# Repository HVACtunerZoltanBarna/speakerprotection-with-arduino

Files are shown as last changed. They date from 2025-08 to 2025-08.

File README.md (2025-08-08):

# speakerprotection-with-arduino
My Arduino based Speaker protection for 4 channels.
AVE !
I am happy to share my project with you. If you use or upgrade it I would be happy if you give some feeback to me just to see how it works around the world:).

So it is an arduino based speaker protection. I use it in my custom made amp, and works well from 2021. Simple and rigid...
You can find here kicad model as well.
What it does?
Protects the speaker from those current whose does not make movement. So protects it from burning.
Topology is:
Amplifier outputs max 4 channel. But can use for less. (An for more as well if you modify the code and use more analogInputs :) )
The voltage from amp output must go to a voltage divided RC filter.
If the AC contains too much DC (or the frequency is extremely low) that can be seen on the capacitor it opens a relay. Normally DC part of the current is 0 so the speakers can move and cool themself.
Just an advice. It is fine to calibrate the inputs with freq generator and power supply for example.
And dont forget about the input voltage of Arduino. The analogRead compares
voltage to Vref. If Supply is too low Vref will lower too.

Bye. Z. :)

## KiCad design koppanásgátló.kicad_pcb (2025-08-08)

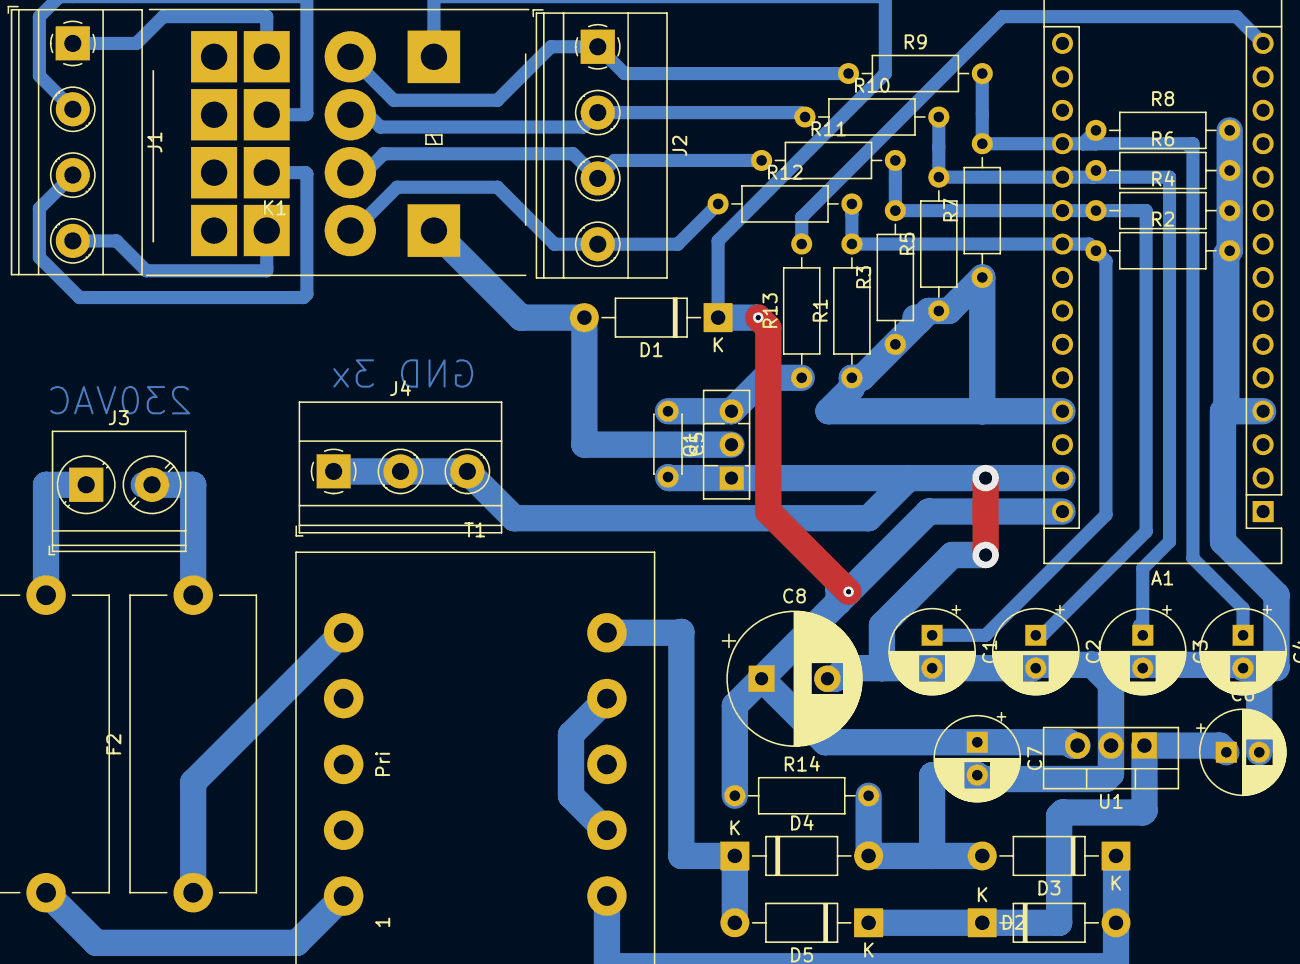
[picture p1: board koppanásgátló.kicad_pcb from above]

Board: 2 copper layers, 38 parts (0 on the bottom side), 26 nets.

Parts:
A1: Arduino_Nano_v3.x; Arduino_Nano
C1, C2, C3, C4, C6, C7: 100uF; CP_Radial_D6.3mm_P2.50mm
C5: 1nF; C_Disc_D4.3mm_W1.9mm_P5.00mm
C8: 2200uF; CP_Radial_D10.0mm_P5.00mm
D1, D2, D3, D4, D5: 1N4001; D_DO-41_SOD81_P10.16mm_Horizontal
F1, F2: Fuse; Fuseholder_Cylinder-5x20mm_Stelvio-Kontek_PTF78_Horizontal_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
J1, J2: Conn_01x04_Female; TerminalBlock_Phoenix_MKDS-1,5-4_1x04_P5.00mm_Horizontal
J3: Conn_01x02_Female; TerminalBlock_Phoenix_PT-1,5-2-5.0-H_1x02_P5.00mm_Horizontal
J4: Conn_01x03_Female; TerminalBlock_Phoenix_MKDS-1,5-3-5.08_1x03_P5.08mm_Horizont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
K1: SCHRACK_PT570012; Relay_4PDT_SCHRACK_PT570012
Q1: BD135; TO-126-3_Vertical
R1, R2, R3, R4, R5, R6, R7, R8, R13: 10K; R_Axial_DIN0207_L6.3mm_D2.5mm_P10.16mm_Horizontal
R9, R10, R11, R12: 82K; R_Axial_DIN0207_L6.3mm_D2.5mm_P10.16mm_Horizontal
R14: 4K7; R_Axial_DIN0207_L6.3mm_D2.5mm_P10.16mm_Horizontal
T1: Transformer_1P_2S; Transformer_CHK_EI30-2VA_2xSec
U1: LM7812_TO220; TO-220-3_Vertical

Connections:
unnamed: A1.15, R13.2
unnamed: A1.19, C4.1, R7.2, R8.1, R9.2
unnamed: A1.20, C3.1, R5.2, R6.1, R10.2
unnamed: A1.21, C2.1, R3.2, R4.1, R11.2
unnamed: A1.22, C1.1, R1.2, R2.1, R12.2
unnamed: A1.27, R1.1, R3.1, R5.1, R7.1
unnamed: A1.4, A1.29, C1.2, C2.2, C3.2, C4.2, C5.2, C6.2, C7.2, C8.2, D3.2, D4.2, J4.1, J4.2, J4.3, Q1.1, R2.2, R4.2, R6.2, R8.2, R14.2, U1.2
unnamed: A1.30, C7.1, C8.1, D1.1, K1.A1, R14.1, U1.3
unnamed: C5.1, Q1.3, R13.1
unnamed: C6.1, D2.1, D5.1, U1.1
unnamed: D1.2, K1.A2, Q1.2
unnamed: D2.2, D3.1, T1.10
unnamed: D4.1, D5.2, T1.6
unnamed: F1.1, T1.1
unnamed: F1.2, J3.1
unnamed: F2.1, T1.5
unnamed: F2.2, J3.2
unnamed: J1.1, K1.14
unnamed: J1.2, K1.24
unnamed: J1.3, K1.34
unnamed: J1.4, K1.44
unnamed: J2.1, K1.11, R9.1
unnamed: J2.2, K1.21, R10.1
unnamed: J2.3, K1.31, R11.1
unnamed: J2.4, K1.41, R12.1
unnamed: T1.7, T1.9

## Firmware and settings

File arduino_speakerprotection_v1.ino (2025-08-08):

//If you use Nano then put UNO bootloader in it.
//the Analog Inputs A0-A3 are attached to AMP output via voltage divider (custom made for you).
// There you need a filter capacitor as well. Above 10Hz AC the procection should not activate.
// there is a 4 pole relay for the 4 channels. When relay is energized, then speakers are connected to amplifier outputs.
//you should calibrate at fix +0,6V all the channels to know how are the measurements (resistors are different in reality).
//you should calibrate at fix +0,6V all the channels to know how are the measurements (resistors are different in reality).

#define maxDCvoltageA0 492
#define maxDCvoltageA1 488
#define maxDCvoltageA2 489
#define maxDCvoltageA3 489
#define minDCvoltageA0 475
#define minDCvoltageA1 472
#define minDCvoltageA2 473
#define minDCvoltageA3 474


#define RelayPin 12

#include<avr/wdt.h> //watchdog timer

// the setup routine runs once when you press reset:
void setup() {

  pinMode(A0, INPUT);
  pinMode(A1, INPUT);
  pinMode(A2, INPUT);
  pinMode(A3, INPUT);
  // initialize serial communication at 9600 bits per second:
  wdt_disable();
  Serial.begin(9600);
   pinMode(RelayPin, OUTPUT);
   digitalWrite(RelayPin, LOW);
   delay(2000);
   wdt_enable(WDTO_500MS);
   wdt_reset();
}

// the loop routine runs over and over again forever:
void loop() {

  
  
  // read the input on analog pin 0:
  int sensorValueA0 = analogRead(A0);
  int sensorValueA1 = analogRead(A1);
  int sensorValueA2 = analogRead(A2);
  int sensorValueA3 = analogRead(A3);

  // print out the value you read:
  Serial.write("A0");
  Serial.println(sensorValueA0);
  Serial.println(sensorValueA1);
  Serial.println(sensorValueA2);
  Serial.println(sensorValueA3);



if (sensorValueA0<minDCvoltageA0 ||sensorValueA0>maxDCvoltageA0 || sensorValueA1<minDCvoltageA1 ||sensorValueA1>maxDCvoltageA1 || sensorValueA2<minDCvoltageA2 ||sensorValueA2>maxDCvoltageA2|| sensorValueA3<minDCvoltageA3 ||sensorValueA3>maxDCvoltageA3){
    AllSpreakersOff();}

digitalWrite(RelayPin, HIGH);
 wdt_reset();  

}

void AllSpreakersOff(void)
{ while(1){
  digitalWrite(RelayPin,LOW);
   wdt_reset();
   }
}
